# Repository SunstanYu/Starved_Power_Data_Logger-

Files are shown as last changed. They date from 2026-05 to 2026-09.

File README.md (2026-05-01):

# Starved Power Data Logger

ESP32-S3 data logger for low-power sensor collection with SD card storage and a local Wi-Fi display mode. The firmware samples soil moisture, DHT11 temperature/humidity, AS7343 spectral channels, and battery voltage, then appends periodic records to a single SD card log file.

## Hardware Target

- Board: Adafruit Feather ESP32-S3 No PSRAM
- Framework: Arduino through PlatformIO
- Storage: SPI SD card by default
- Sensors:
  - DHT11 temperature/humidity sensor
  - Analog soil moisture sensor
  - SparkFun AS7343 spectral sensor over I2C
- Battery monitor: ADC voltage divider, expected 200k upper / 100k lower

## Pin Map

| Function | Pin |
| --- | --- |
| Mode switch | GPIO5 |
| DHT11 data | A3 |
| Soil moisture ADC | A4 |
| Battery ADC | A2 |
| SD card CS | T12 |
| Battery LED | T13 |
| Peripheral switch 1 | T10 |
| Peripheral switch 2 | T6 |
| Peripheral switch 3 | T9 |
| AS7343 I2C SDA | GPIO3 |
| AS7343 I2C SCL | GPIO4 |

The SD card uses the board's default SPI pins. Only CS is configured explicitly.

## Operating Modes

GPIO5 selects the runtime mode:

- LOW: logger mode
- HIGH: local display mode

In logger mode, the device samples sensors, records data periodically, then enters timed deep sleep. GPIO5 is also configured as an EXT0 wake source, so driving GPIO5 HIGH can wake the device into display mode.

In display mode, the ESP32-S3 starts a local Wi-Fi access point and serves a dashboard from the device.

Display access point:

- SSID: `ESP32S3-Gateway`
- Password: `12345678`
- URL: `http://192.168.10.1/`

To leave display mode, hold GPIO5 LOW for 5 seconds. The firmware restarts and returns to logger mode.

## Sampling and Storage

Current logger timing:

- Awake window: 20 seconds
- Deep sleep duration: 10 seconds
- Record interval: every 50 samples

Storage mode is currently SD card:

```cpp
const int STORAGE_MODE = 0;
```

The SD card is initialized with a conservative SPI frequency:

```cpp
SD.begin(SDcardPin, SPI, 1000000);
```

Records are appended to:

```text
/sensor_log.txt
```

## Log Format

Each record is one line of comma-separated `key=value` fields:

```text
time_ms=23034,time=2027-02-13 01:31:08,sensor=Soil moisture + DHT11 + AS7343,sample_count=100,moisture=4095,voltage_mv=4670,temp_c=24.1,humidity=23.0,spectral=0|0|0|0|0|2|0|0|0|0|0|2|0|0|0|0|0|2
```

Fields:

- `time_ms`: milliseconds since the current boot
- `time`: system time if the ESP32 time source is valid
- `sensor`: sensor stack label
- `sample_count`: retained sample counter
- `moisture`: raw ADC reading from the soil moisture sensor
- `voltage_mv`: calculated battery voltage in millivolts
- `temp_c`: DHT11 temperature in Celsius, or `nan` on failed read
- `humidity`: DHT11 relative humidity, or `nan` on failed read
- `spectral`: AS7343 channel values separated by `|`

Note: `time_ms` resets after deep sleep because the chip restarts. The `time` field is only trustworthy after a valid time source is configured.

## Battery Voltage Calculation

The firmware assumes a 200k / 100k divider:

```text
Vadc = Vbat / 3
Vbat = Vadc * 3
```

The calculation is:

```cpp
int raw = analogRead(batteryAdcPin);
float vadc = ((float)raw / 4095.0f) * 3.3f;
float vbat = vadc * 3.0f;
int batteryMv = (int)(vbat * 1000.0f);
```

ADC setup:

```cpp
analogReadResolution(12);
analogSetPinAttenuation(batteryAdcPin, ADC_11db);
```

The battery measurement point should be the battery positive terminal through the divider. Do not hard-wire USB/VBUS and the battery positive terminal together unless the board's power path explicitly supports that connection.

## Build and Upload

Install PlatformIO, then run:

```sh
pio run
```

Upload to the board:

```sh
pio run --target upload
```

Open the serial monitor:

```sh
pio device monitor --baud 115200
```

## Project Layout

```text
.
├── platformio.ini
├── partitions.csv
├── src
│   ├── main.cpp
│   ├── display_gateway.cpp
│   └── display_gateway.h
├── include
├── lib
└── test
```

## Notes

- `.pio` build output is ignored by Git.
- The project includes an FFat partition, but the active storage mode is SD card.
- The display dashboard reads the same storage source used by the logger.
- If the AS7343 values saturate, reduce gain or integration time in the sensor configuration.
- If soil moisture stays near 4095, verify the sensor output range and ADC wiring.

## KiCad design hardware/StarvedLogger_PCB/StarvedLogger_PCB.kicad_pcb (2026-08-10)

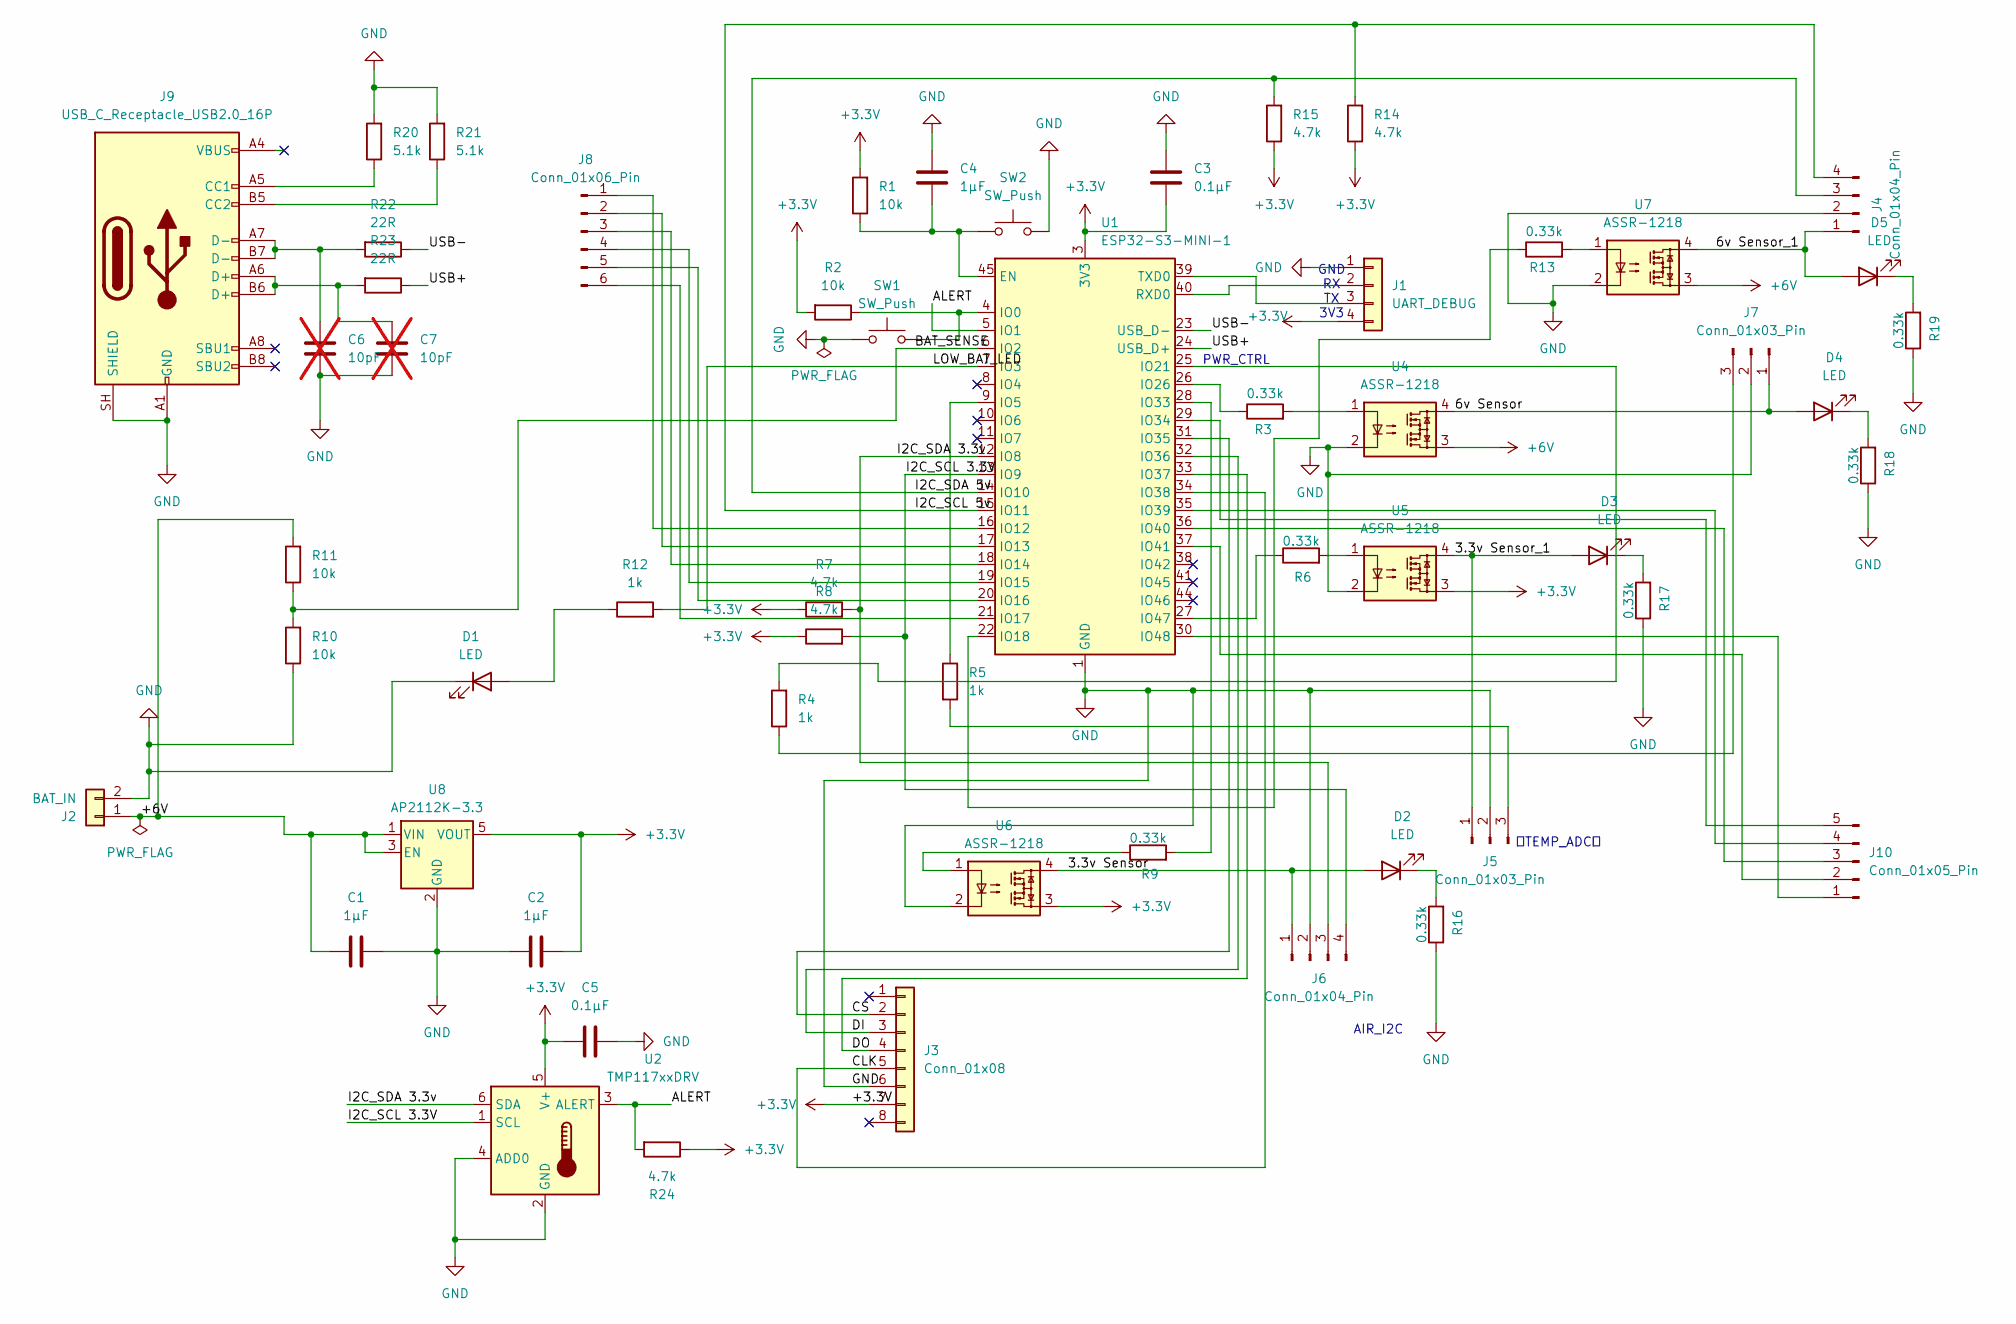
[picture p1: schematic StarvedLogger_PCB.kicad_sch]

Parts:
C1, C2, C4: 1µF; C_0603_1608Metric
C3, C5: 0.1µF; C_0603_1608Metric
C6, C7: 10pF; C_0603_1608Metric; not fitted
D1, D2, D3, D4, D5: LED; LED_0603_1608Metric
J1: UART_DEBUG; PinHeader_1x04_P2.54mm_Vertical
J2: BAT_IN; PinHeader_1x02_P2.54mm_Vertical
J3: Conn_01x08; PinHeader_1x08_P2.54mm_Vertical
J4, J6: Conn_01x04_Pin; PinHeader_1x04_P2.54mm_Vertical
J5, J7: Conn_01x03_Pin; PinHeader_1x03_P2.54mm_Vertical
J8: Conn_01x06_Pin; PinHeader_1x06_P2.54mm_Vertical
J9: USB_C_Receptacle_USB2.0_16P; USB_C_Receptacle_Amphenol_12401610E4-2A_CircularHoles
J10: Conn_01x05_Pin; PinHeader_1x05_P2.54mm_Vertical
R1, R2, R10, R11: 10k; R_0603_1608Metric
R3, R6, R9, R13, R16, R17, R18, R19: 0.33k; R_0603_1608Metric
R4, R5, R12: 1k; R_0603_1608Metric
R7, R8, R14, R15, R24: 4.7k; R_0603_1608Metric
R20, R21: 5.1k; R_0603_1608Metric
R22, R23: 22R; R_0603_1608Metric
SW1, SW2: SW_Push; SW_SPST_TL3342
U1: ESP32-S3-MINI-1
U2: TMP117xxDRV; WSON-6-1EP_2x2mm_P0.65mm_EP1x1.6mm
U4, U5, U6, U7: ASSR-1218; SO-4_4.4x4.3mm_P2.54mm
U8: AP2112K-3.3; SOT-23-5

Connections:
+3.3V: C2.2, C3.2, C5.1, J1.4, J3.7, R1.2, R2.2, R7.1, R8.1, R14.1, R15.1, R24.1, U1.3 (3V3), U2.5 (V+), U5.3, U6.3, U8.5 (VOUT)
+6V: C1.1, J2.1, R11.2, U4.3, U7.3, U8.1 (VIN), U8.3 (EN)
/3.3v Sensor: D2.2 (A), J6.1, U6.4
/3.3v Sensor_1: D3.2 (A), J5.1, U5.4
/6v Sensor: D4.2 (A), J7.1, U4.4
/6v Sensor_1: D5.2 (A), J4.1, U7.4
/ALERT: R24.2, U1.5 (IO1), U2.3 (ALERT)
/BAT_SENSE: R10.2, R11.1, U1.6 (IO2)
/CLK: J3.5, U1.34 (IO38)
/CS: J3.2, U1.31 (IO35)
/DI: J3.3, U1.32 (IO36)
/DO: J3.4, U1.33 (IO37)
/I2C_SCL 3.3V: J6.4, R8.2, U1.13 (IO9), U2.1 (SCL)
/I2C_SCL 5v: J4.4, R14.2, U1.15 (IO11)
/I2C_SDA 3.3v: J6.3, R7.2, U1.12 (IO8), U2.6 (SDA)
/I2C_SDA 5v: J4.3, R15.2, U1.14 (IO10)
/LOW_BAT_LED: R12.2, U1.7 (IO3)
/USB+: R23.1, U1.24 (USB_D+)
/USB-: R22.1, U1.23 (USB_D-)
GND: C1.2, C2.1, C3.1, C4.1, C5.2, C6.1, C7.1, D1.1 (K), J1.1, J2.2, J3.6, J4.2, J5.2, J6.2, J7.2, J9.A1 (GND), J9.A12 (GND), J9.B1 (GND), J9.B12 (GND), J9.SH (SHIELD), R10.1, R16.1, R17.1, R18.1, R19.1, R20.2, R21.2, SW1.1, SW2.2, U1.1 (GND), U1.2 (GND), U1.42 (GND), U1.43 (GND), U1.46 (GND), U1.47 (GND), U1.48 (GND), U1.49 (GND), U1.50 (GND), U1.51 (GND), U1.52 (GND), U1.53 (GND), U1.54 (GND), U1.55 (GND), U1.56 (GND), U1.57 (GND), U1.58 (GND), U1.59 (GND), U1.60 (GND), U1.61 (GND), U1.62 (GND), U1.63 (GND), U1.64 (GND), U1.65 (GND), U2.2 (GND), U2.4 (ADD0), U4.2, U5.2, U6.2, U7.2, U8.2 (GND)
unnamed: C6.2, J9.A7 (D-), J9.B7 (D-), R22.2
unnamed: C7.2, J9.A6 (D+), J9.B6 (D+), R23.2
unnamed: D1.2 (A), R12.1
unnamed: D2.1 (K), R16.2
unnamed: D3.1 (K), R17.2
unnamed: D4.1 (K), R18.2
unnamed: D5.1 (K), R19.2
unnamed: J1.2, U1.40 (RXD0)
unnamed: J1.3, U1.39 (TXD0)
unnamed: J5.3, R5.2
unnamed: J7.3, R4.1
unnamed: J8.1, U1.16 (IO12)
unnamed: J8.2, U1.17 (IO13)
unnamed: J8.3, U1.18 (IO14)
unnamed: J8.4, U1.19 (IO15)
unnamed: J8.5, U1.20 (IO16)
unnamed: J8.6, U1.21 (IO17)
unnamed: J9.A5 (CC1), R20.1
unnamed: J9.B5 (CC2), R21.1
unnamed: J10.1, U1.30 (IO48)
unnamed: J10.2, U1.37 (IO41)
unnamed: J10.3, U1.36 (IO40)
unnamed: J10.4, U1.35 (IO39)
unnamed: J10.5, U1.29 (IO34)
unnamed: R3.2, U4.1
unnamed: R6.2, U5.1
unnamed: R9.1, U6.1
unnamed: R13.2, U7.1
unnamed: C4.2, R1.1, SW2.1, U1.45 (EN)
unnamed: R2.1, SW1.2, U1.4 (IO0)
unnamed: R5.1, U1.9 (IO5)
unnamed: R13.1, U1.22 (IO18)
unnamed: R4.2, U1.25 (IO21)
unnamed: R3.1, U1.26 (IO26)
unnamed: R9.2, U1.28 (IO33)
unnamed: R6.1, U1.27 (IO47)

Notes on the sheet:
AIR_I2C
PWR_CTRL
GND RX TX 3V3
（TEMP_ADC）

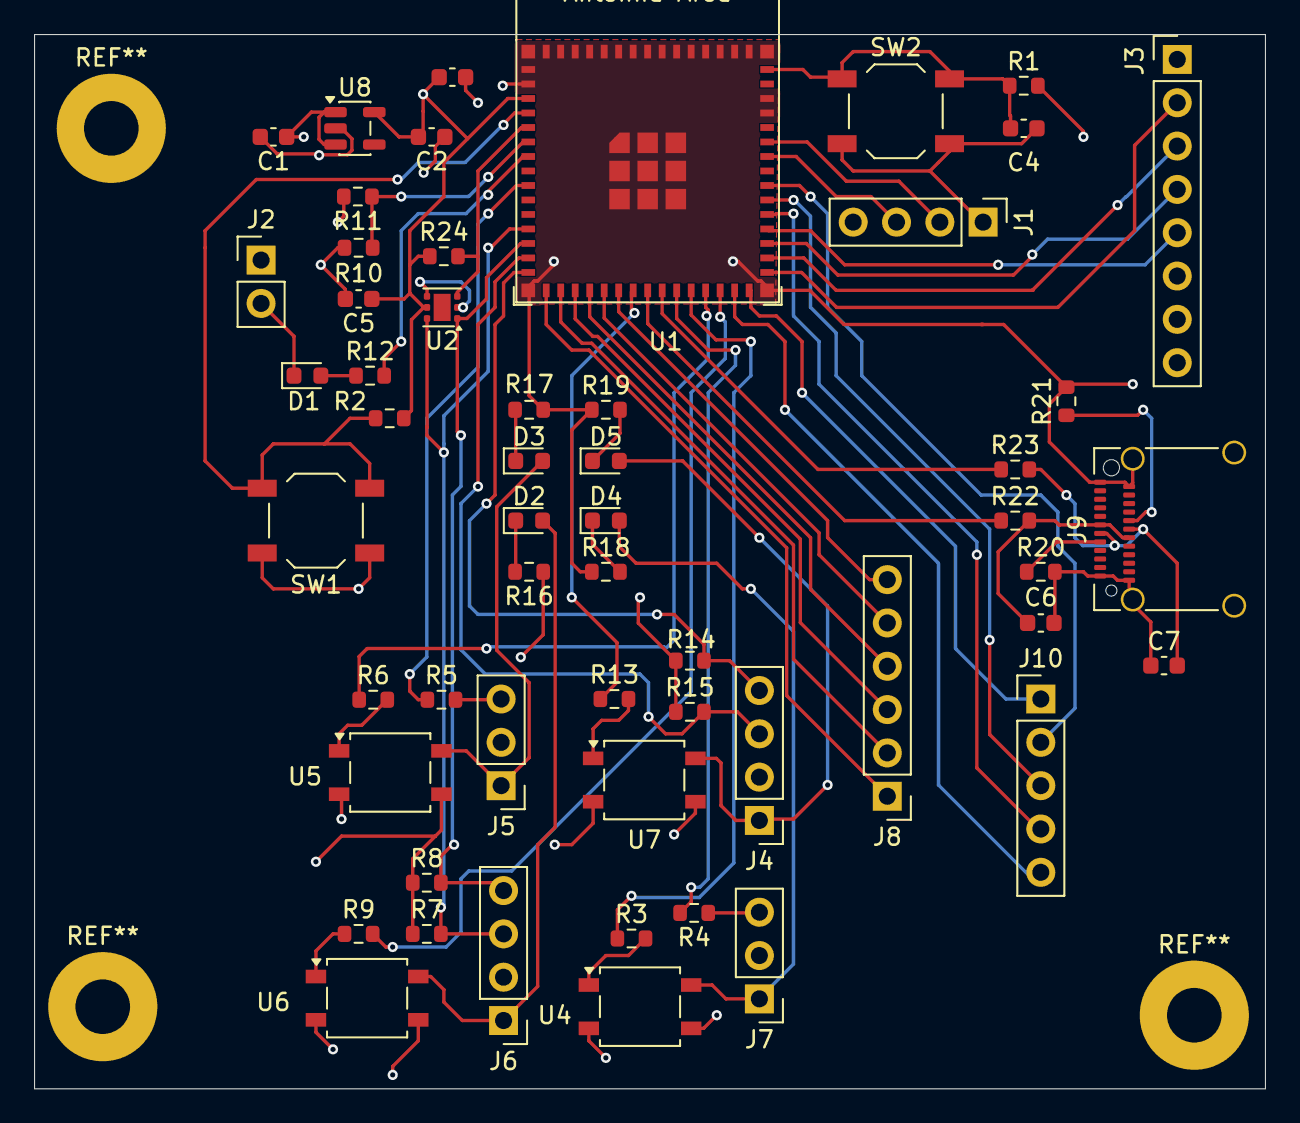
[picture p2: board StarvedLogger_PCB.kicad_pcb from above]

Board: 4 copper layers, 72.2 x 61.8 mm, 55 parts (0 on the bottom side), 56 nets.

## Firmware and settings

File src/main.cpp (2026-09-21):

#include <Arduino.h>
#include "esp_sleep.h"
#include "driver/gpio.h"  // for access to gpio_num_t / GPIO_NUM_6
#include <SPI.h>
#include <SD.h>
#include <FFat.h>
#include <Wire.h>
#include <DHTesp.h>
#include <SparkFun_AS7343.h>
#include <time.h>
#include "display_gateway.h"
#include "tasks.h"

// ====================== CONSTANTS & PINS ======================
const uint64_t SLEEP_DURATION_US = 10 * 1000000;   // sleep for 10 seconds
const uint32_t AWAKE_DURATION_MS = 20 * 1000;      // awake for 20 seconds
const uint32_t MODE_SWITCH_DELAY_MS = 5000;         // GPIO5 must stay LOW for 5s before leaving display mode
const uint32_t RECORD_EVERY_SAMPLE_COUNT = 50;      // write one record every 50 samples
const int STORAGE_MODE = 0;                         // 0 = SD card, 1 = FFat flash
int led = LED_BUILTIN;
const gpio_num_t modePin = GPIO_NUM_5;              // LOW = logger mode, HIGH = display mode

const int switch1Pin = T10;
const int switch2Pin = T6;
const int switch3Pin = T9;
const int batteryLedPin = T13;


const int sensor1Pin = A3;   // DHT11 data pin, use the real GPIO number 
const int sensor2Pin = A4;    // soil moisture sensor analog input
const int SDcardPin = T12;
const int batteryAdcPin = A2;
const char* DISPLAY_SENSOR_TYPE = "Soil moisture + DHT11 + AS7343";
const char* DISPLAY_DATA_FILE = "/sensor_log.txt";
const float ADC_VREF = 3.3f;
const float BATTERY_DIVIDER_RATIO = 3.0f;
const float BATTERY_LOW_THRESHOLD_V = 4.0f;

// ★ A5：低电压截止。
//
// 供电是 4 节 AA（标称 6.0V）。碱性电池没有锂电「过放即报废」的问题，
// 所以这里的理由不是保护电池，而是【保护数据】：
// 电压掉到 3.3V LDO 的压差余量以下时，轨会不稳；如果恰好发生在
// SD 写入中途，坏的是文件甚至整张卡——而那是几个月的数据。
//
// 所以到阈值就：刷掉待写数据 → 点亮低电量灯 → 进【无定时唤醒】的深睡。
// 不设定时器意味着它不会再自己醒来采样，只能靠 EXT0（人拨开关）或换电池。
// extern：C++ 里命名空间作用域的 const 默认是【内部链接】，
// 不加 extern 的话 tasks.cpp 链接时找不到它。
extern const float BATTERY_CUTOFF_V = 3.7f;

// ★ A5 修（2026-09-20 上板实测发现）
//
// 【现象】把固件烧进一块【没接电池】的裸板，上电不到 1 秒就永久睡死，
// USB 从系统里彻底消失，esptool 也够不着，只能按 RESET 救。
//
// 【原因】判据写的是 `batteryMv > 0`，本意是「读数有效」。
// 但 batteryAdcPin 悬空时 ADC 不读 0 —— 它读到的是几百 mV 的噪声。
// 于是 `> 0 && < 3700` 成立，节点认为自己没电了，执行永久停机。
//
// 【为什么这在田里是致命的】分压电阻虚焊、接插件松动、电池仓接触不良 ——
// 任何一种都会让 ADC 悬空，节点就把自己变成砖，而且【没有唤醒源】，
// 必须有人走到田里按复位。本来是保护数据的机制，变成了失效机制。
//
// 两道闸：
//   ① 合理性下限：4 节 AA 经 ÷3 分压，哪怕快没电也在 3V 以上。
//      读到低于 1V 说明【没接电池 / ADC 悬空】，不是「电池空了」。
//   ② 连续判定：单次 ADC 毛刺不该让一个田间节点停机。
// ★ 第二次修（第一次的判据是错的，上板又睡死一次才发现）
//
// 第一版下限设 1000mV，依据是「悬空 ADC 读数低」。**这个假设不成立** ——
// 悬空引脚读的是随机的中间值，不是 0 附近。分压比 3:1，ADC 只要落在
// 0.33~1.23V，换算出来就是 1.0~3.7V，正好落进低电量窗口，
// 连续 3 次照样停机。加了连续判定只是把「1 秒睡死」变成「90 秒睡死」。
//
// 【按物理量重新定界】供电是 4 节 AA 碱性电池：
//     满电 6.4V ·  标称 6.0V ·  0.9V/节 = 3.6V 已经耗尽
// 所以 3.7V 截止是对的。但 3.0V（0.75V/节）是**深度放空**，
// 一个还能跑 WiFi 的节点不可能读到这个值 —— 读到就说明【线路断了】，
// 不是电池空了。下限提到 3000mV，可动作窗口变成 3.0~3.7V。
//
// 【再加一道：稳定性】电平本身区分不了悬空和真电压，但**噪声能**：
// 接了电池经分压出来的读数是稳的，悬空引脚会飘。
// 所以不只要连续 3 次低，还要这 3 次的极差小于 300mV。
const int BATTERY_SANITY_FLOOR_MV = 3000;   // 0.75V/节 = 深度放空，读到只能是线路断了
const int BATTERY_LOW_STREAK = 3;           // 连续 3 次
const int BATTERY_STABLE_SPREAD_MV = 300;   // 这 3 次的极差上限——悬空会飘，电池不会

// 返回 true 表示「确实该停机了」。
bool batteryShouldShutdown(int batteryMv) {
  static int streak = 0;
  static int lo = 0, hi = 0;

#ifdef BENCH_NO_BATTERY
  // ★ 独立开关，不再跟 FORCE_DISPLAY_MODE 绑在一起。
  //
  // 这两个是【两件事】：FORCE_DISPLAY_MODE 是「没接跳线」，
  // BENCH_NO_BATTERY 是「没接电池」。第一版把旁路写在
  // #ifdef FORCE_DISPLAY_MODE 里，结果台面验证时这个函数【一进来就返回】，
  // 下面那两道判据（合理性下限、稳定性）一次都没在真硬件上跑过 ——
  // 而它们恰恰是那个把板子睡死两次的 bug 的修复本身。
  //
  // 耦合两个无关的开关，等于让其中一个永远测不到。
  Serial.printf("[BAT] %d mV (bench: low-battery shutdown disabled)\n", batteryMv);
  return false;
#endif

  if (batteryMv < BATTERY_SANITY_FLOOR_MV) {
    streak = 0;
    Serial.printf("[BAT] %d mV below sanity floor %d -> NO BATTERY / wiring fault, "
                  "not low battery\n", batteryMv, BATTERY_SANITY_FLOOR_MV);
    return false;                       // 线路断了，绝不停机
  }
  if (batteryMv >= (int)(BATTERY_CUTOFF_V * 1000)) {
    streak = 0;
    return false;
  }

  if (streak == 0) { lo = hi = batteryMv; }
  else { if (batteryMv < lo) lo = batteryMv; if (batteryMv > hi) hi = batteryMv; }
  streak++;

  if (streak < BATTERY_LOW_STREAK) {
    Serial.printf("[BAT] %d mV below cutoff (%d/%d) — waiting for confirmation\n",
                  batteryMv, streak, BATTERY_LOW_STREAK);
    return false;
  }
  if (hi - lo > BATTERY_STABLE_SPREAD_MV) {
    Serial.printf("[BAT] readings unstable (spread %d mV > %d) -> floating pin, "
                  "not a dying battery\n", hi - lo, BATTERY_STABLE_SPREAD_MV);
    streak = 0;
    return false;                       // 飘 = 悬空，不是电池在掉电
  }
  return true;
}
DHTesp dht;
SfeAS7343ArdI2C spectralSensor;
uint16_t spectralChannels[ksfAS7343NumChannels];
// const int wakePin   = T6;    // D6 = GPIO6 (used as normal input + DeepSleep wakeup)
bool forever_awake  = false; // never sleep after D6 is triggered

bool sdReady = false;
bool flashReady = false;
bool spectralReady = false;
bool displayModeActive = false;
bool tasksRunning = false;      // ★ A8：四任务是否起来了
bool modePinLowTiming = false;
unsigned long modePinLowStartMs = 0;
RTC_DATA_ATTR uint32_t sampleCounter = 0;

// ====================== HELPERS ======================

// ★ A10：OTA 回滚自检。
//
// Arduino 核心已启用 CONFIG_BOOTLOADER_APP_ROLLBACK_ENABLE：新固件首次
// 启动时处于 PENDING_VERIFY 状态，initArduino() 会调 verifyOta()——
// 返回 true 就 mark_app_valid 确认，返回 false 就【自动回滚并重启】到旧分区。
//
// 但核心里的 verifyOta() 是 weak 函数，默认无条件 `return true`：
// 只要新固件能跑到 initArduino() 就算通过。这挡得住「根本起不来」，
// 挡不住「能起来但功能坏了」。
//
// 对一个埋在田里、回收成本极高的节点，这个区别是致命的——
// 刷坏了就是报废，没有第二次机会。所以覆盖它，做真实自检。
//
// ⚠️ 核心注释提醒：这函数在启动早期跑，要短、不要阻塞太久。
// 所以这里只做「能不能起来」级别的检查，不碰 2.5s 的 DHT11 时序。
extern "C" bool verifyOta() {
  Serial.println("[OTA] verifying new image...");

  pinMode(SDcardPin, OUTPUT);
  digitalWrite(SDcardPin, HIGH);
  if (!SD.begin(SDcardPin, SPI, 1000000)) {
    Serial.println("[OTA] FAIL: SD not available -> rollback");
    return false;                          // 存储起不来 = 数据会丢，不如退回
  }
  SD.end();

  // 同一个坑：`mv > 0` 挡不住悬空 ADC。分压虚焊会让每次 OTA 都无条件回滚，
  // 而回滚是【静默】的 —— 你只会看到"升级没生效"，查不到为什么。
  int mv = getBatteryMv();
  if (mv >= BATTERY_SANITY_FLOOR_MV && mv < (int)(BATTERY_CUTOFF_V * 1000)) {
    Serial.printf("[OTA] FAIL: battery %d mV too low -> rollback\n", mv);
    return false;                          // 电量不够撑过验证期，别冒险留在新版
  }

  Serial.println("[OTA] image verified, cancelling rollback.");
  return true;
}

// ★ A5：电量到底线时的收尾动作。调用后不返回。
void enterLowBatteryShutdown(int batteryMv) {
  Serial.printf("[BAT] %d mV below cutoff %.2f V — flushing and halting.\n",
                batteryMv, BATTERY_CUTOFF_V);
  digitalWrite(batteryLedPin, HIGH);
  setPeripheralSwitches(false);          // 先断外设，减少残余放电
  Serial.flush();

  // ★ 改：留一个【很长周期】的定时唤醒，而不是彻底不醒。
  //
  // 原设计是无唤醒源，理由是「不会再自己醒来采样」。但那等于
  // 把「需要人工干预」写死进固件 —— 而碱性电池在低温下电压会回升，
  // 白天升温后可能又能撑一阵；分压虚焊修好后也该能自己恢复。
  //
  // 6 小时醒一次只是读个 ADC 再睡，占空比接近 0，
  // 对续航的影响可以忽略，换来的是【可恢复】。
  esp_sleep_enable_timer_wakeup(6ULL * 3600ULL * 1000000ULL);
  esp_deep_sleep_start();
}

// ★ A6：资源水位。诊断「跑久了会不会崩」只能靠这个，不能靠推测。
//
// getMinFreeHeap() 是【历史最低值】——它回答的是「最危险的那一刻离
// OOM 还有多远」，比当前空闲值有用得多。栈水位同理：uxTaskGetStack-
// HighWaterMark 返回的是该任务栈的历史最小剩余字节。
void logResourceWatermark(const char* tag) {
  Serial.printf("[MEM] %s heap=%u min=%u largest=%u stack_free=%u\n",
                tag,
                ESP.getFreeHeap(),
                ESP.getMinFreeHeap(),                        // 历史最低 ← 关键
                ESP.getMaxAllocHeap(),                       // 最大连续块 ← 看碎片
                uxTaskGetStackHighWaterMark(NULL) * sizeof(StackType_t));
}

// ★ A4：Task WDT。田里的节点卡死 = 报废，只能人去拔电池。
//
// Arduino 默认【关掉】了 task WDT（原型阶段谁也不想跑着跑着被复位），
// 但生产设备必须有人盯着「卡死」这件事：SD 总线卡住、传感器不应答、
// 某个 while 等不到条件——这些都不会自己恢复。
//
// 采样态与显示态的超时不同：采样一轮含 2.5s 的外设稳定与 DHT11 时序，
// 显示态则是持续响应 HTTP。所以由调用方给超时值。
#include "esp_task_wdt.h"

void watchdogBegin(uint32_t timeout_s) {
#if ESP_IDF_VERSION_MAJOR >= 5
  esp_task_wdt_config_t cfg = {
      .timeout_ms = timeout_s * 1000,
      .idle_core_mask = 0,          // 不监控 idle 任务
      .trigger_panic = true,        // 超时直接 panic 复位（现场会进 coredump）
  };
  esp_task_wdt_reconfigure(&cfg);
#else
  esp_task_wdt_init(timeout_s, true);
#endif
  esp_task_wdt_add(NULL);           // 把当前任务纳入监控
  Serial.printf("[WDT] armed, timeout=%us\n", timeout_s);
}

void watchdogFeed() { esp_task_wdt_reset(); }
void setPeripheralSwitches(bool enabled) {
  digitalWrite(switch1Pin, enabled ? HIGH : LOW);
  digitalWrite(switch2Pin, enabled ? HIGH : LOW);
  digitalWrite(switch3Pin, enabled ? HIGH : LOW);
  Serial.printf(
    "[PWR] switch1=%s switch2=%s switch3=%s\n",
    enabled ? "HIGH" : "LOW",
    enabled ? "HIGH" : "LOW",
    enabled ? "HIGH" : "LOW"
  );
}

// GPIO5 is the single hardware mode selector for the whole firmware:
// - LOW  => sensor logger mode
// - HIGH => local display gateway mode
bool isDisplayModeRequested() {
#ifdef FORCE_DISPLAY_MODE
  // 测试钩子：常驻模式要求 GPIO5 拉高，而那需要一根跳线。
  // 开这个宏可以在没有跳线的台面上验证四任务架构本身。
  // 只由 -DFORCE_DISPLAY_MODE 打开，正常构建里这段不存在。
  return true;
#endif
  return digitalRead((int)modePin) == HIGH;
}

void printWakeupReason() {
  esp_sleep_wakeup_cause_t cause = esp_sleep_get_wakeup_cause();
  switch (cause) {
    case ESP_SLEEP_WAKEUP_EXT0:
      Serial.println("[WAKE] Wakeup caused by EXT0 (GPIO5 HIGH).");
      break;
    case ESP_SLEEP_WAKEUP_TIMER:
      Serial.println("[WAKE] Wakeup caused by timer.");
      break;
    default:
      Serial.printf("[WAKE] Wakeup was not caused by deep sleep: %d\n", (int)cause);
      break;
  }
}

// Logger mode uses both wake sources:
// 1. timer wakeup for the next sampling cycle
// 2. EXT0 wakeup on GPIO5 HIGH so the user can force display mode while asleep
void configureWakeSources() {
  esp_sleep_enable_timer_wakeup(SLEEP_DURATION_US);
  esp_sleep_enable_ext0_wakeup(modePin, 1);
}

// A reboot is the cleanest way to switch modes at runtime because setup()
// re-runs the same initialization path and re-evaluates GPIO5.
void restartForModeSwitch(const char* reason) {
  Serial.println(reason);
  Serial.flush();
  delay(100);
  ESP.restart();
}

void enterTimedDeepSleep() {
  Serial.println("[SLEEP] Preparing to enter deep sleep...");
  configureWakeSources();
  Serial.println("[SLEEP] Entering deep sleep now.");
  Serial.flush();
  delay(100);
  esp_deep_sleep_start();
}

int getMoisture() {
  int value = analogRead(sensor2Pin);
  Serial.print("Soil moisture raw value: ");
  Serial.println(value);
  return value;
}

int getBatteryMv() {
  int raw = analogRead(batteryAdcPin);
  float vadc = ((float)raw / 4095.0f) * ADC_VREF;
  float vbat = vadc * BATTERY_DIVIDER_RATIO;
  int batteryMv = (int)(vbat * 1000.0f);

  Serial.print("[BAT] RAW=");
  Serial.print(raw);
  Serial.print(" Vbat=");
  Serial.print(vbat, 3);
  Serial.println(" V");

  digitalWrite(batteryLedPin, vbat < BATTERY_LOW_THRESHOLD_V ? HIGH : LOW);
  Serial.printf("[BAT] T13=%s\n", vbat < BATTERY_LOW_THRESHOLD_V ? "HIGH" : "LOW");

  return batteryMv;
}

bool readDht11(float& temperatureC, float& humidity) {
  Serial.println("[DHT11] Reading...");
  TempAndHumidity data = dht.getTempAndHumidity();
  humidity = data.humidity;
  temperatureC = data.temperature;

  if (isnan(humidity) || isnan(temperatureC)) {
    Serial.println("[DHT11] Failed to read from DHT11");
    return false;
  }

  Serial.print("[DHT11] Temperature: ");
  Serial.print(temperatureC);
  Serial.print(" C, Humidity: ");
  Serial.print(humidity);
  Serial.println(" %");
  return true;
}

bool initSpectralSensor() {
  Serial.println("[AS7343] Initializing...");
  Wire.begin(3,4);
  Wire.setClock(100000);

  if (!spectralSensor.begin(0x39, Wire)) {
    Serial.println("[AS7343] begin failed.");
    return false;
  }
  if (!spectralSensor.powerOn()) {
    Serial.println("[AS7343] powerOn failed.");
    return false;
  }
  if (!spectralSensor.setAutoSmux(AUTOSMUX_18_CHANNELS)) {
    Serial.println("[AS7343] setAutoSmux failed.");
    return false;
  }
  if (!spectralSensor.enableSpectralMeasurement()) {
    Serial.println("[AS7343] enableSpectralMeasurement failed.");
    return false;
  }

  Serial.println("[AS7343] Sensor ready.");
  return true;
}

int readSpectralChannels(uint16_t* channels, size_t channelCapacity) {
  if (!spectralReady) {
    return 0;
  }

  if (!spectralSensor.readSpectraDataFromSensor()) {
    Serial.println("[AS7343] readSpectraDataFromSensor failed.");
    return 0;
  }

  int count = spectralSensor.getData(channels);
  if (count > (int)channelCapacity) {
    count = (int)channelCapacity;
  }

  Serial.print("[AS7343] Channels: ");
  for (int i = 0; i < count; i++) {
    Serial.print(channels[i]);
    if (i + 1 < count) {
      Serial.print(",");
    }
  }
  Serial.println();
  return count;
}

bool initSdCard() {
  Serial.printf("[SD] Initializing with CS pin %d...\n", SDcardPin);
  SPI.begin();
  pinMode(SDcardPin, OUTPUT);
  digitalWrite(SDcardPin, HIGH);
  if (!SD.begin(SDcardPin, SPI, 1000000)) {
    Serial.println("[SD] SD.begin failed.");
    return false;
  }
  Serial.println("[SD] SD.begin OK.");
  return true;
}

bool initFlashStorage() {
  Serial.println("[FFat] Mounting flash storage...");
  if (!FFat.begin(true)) {
    Serial.println("[FFat] FFat.begin failed.");
    return false;
  }
  Serial.println("[FFat] FFat mounted OK.");
  return true;
}

bool isStorageReady() {
  return STORAGE_MODE == 0 ? sdReady : flashReady;
}

const char* getStorageName() {
  return STORAGE_MODE == 0 ? "SD" : "FFat";
}

String getDisplayStorageLabel() {
  return STORAGE_MODE == 0 ? "SD card log" : "FFat flash files";
}

String buildMeasurementRecord(
  int moisture,
  int batteryMv,
  float temperatureC,
  float humidity,
  bool dhtOk,
  const uint16_t* channels,
  int channelCount
) {
  time_t now = time(nullptr);
  struct tm timeinfo;
  String record;

  record += "time_ms=";
  record += String(millis());
  if (now > 1700000000 && localtime_r(&now, &timeinfo) != nullptr) {
    char timestamp[24];
    snprintf(
      timestamp,
      sizeof(timestamp),
      "%04d-%02d-%02d %02d:%02d:%02d",
      timeinfo.tm_year + 1900,
      timeinfo.tm_mon + 1,
      timeinfo.tm_mday,
      timeinfo.tm_hour,
      timeinfo.tm_min,
      timeinfo.tm_sec
    );
    record += ",time=";
    record += timestamp;
  }
  record += ",sensor=";
  record += DISPLAY_SENSOR_TYPE;
  record += ",sample_count=";
  record += String(sampleCounter);
  record += ",moisture=";
  record += String(moisture);
  record += ",voltage_mv=";
  record += String(batteryMv);
  // ★ A7：显式的数据质量位。
  //
  // 原来读失败写 "nan"，但下游分不清三件事：传感器读失败、传感器真的
  // 返回了 NaN、解析出错。在 esp32-autoflash 的评测里正好栽过同一个坑
  // ——「读数恒 0」到底是代码写坏了还是传感器坏了，只看数值无法归因。
  // 带上质量位，归因就从「猜」变成「读一个字段」。
  record += ",temp_c=";
  record += dhtOk ? String(temperatureC, 1) : String("nan");
  record += ",humidity=";
  record += dhtOk ? String(humidity, 1) : String("nan");
  record += ",dht_q=";
  record += dhtOk ? "ok" : "read_fail";
  // ★ A3：时钟来源。没对过时只有相对时间（time_ms + 采样序号），
  // 下游据此判断 time= 字段可不可信，而不是看到有值就当真。
  record += ",clk=";
  record += (now > 1700000000) ? "synced" : "uptime_only";
  record += ",spectral=";
  if (channelCount > 0) {
    for (int i = 0; i < channelCount; i++) {
      record += String(channels[i]);
      if (i + 1 < channelCount) {
        record += "|";
      }
    }
  } else {
    record += "none";
  }
  return record;
}

String buildFlashRecordPath() {
  time_t now = time(nullptr);
  struct tm timeinfo;
  char path[48];

  if (now > 1700000000 && localtime_r(&now, &timeinfo) != nullptr) {
    snprintf(
      path,
      sizeof(path),
      "/%04d%02d%02d_%02d%02d%02d.txt",
      timeinfo.tm_year + 1900,
      timeinfo.tm_mon + 1,
      timeinfo.tm_mday,
      timeinfo.tm_hour,
      timeinfo.tm_min,
      timeinfo.tm_sec
    );
  } else {
    snprintf(path, sizeof(path), "/sample_%010lu_%010lu.txt", (unsigned long)sampleCounter, (unsigned long)millis());
  }

  return String(path);
}

void appendMeasurementToSd(const String& record) {
  if (!sdReady) {
    return;
  }

  File file = SD.open(DISPLAY_DATA_FILE, FILE_APPEND);
  if (!file) {
    Serial.println("[SD] Open display data file failed.");
    return;
  }

  file.println(record);
  file.close();
  Serial.println("[SD] Measurement appended.");
}

void writeMeasurementToFlash(const String& record) {
  if (!flashReady) {
    return;
  }

  String path = buildFlashRecordPath();
  File file = FFat.open(path.c_str(), FILE_WRITE);
  if (!file) {
    Serial.printf("[FFat] Open flash data file failed: %s\n", path.c_str());
    return;
  }

  file.println(record);
  file.close();
  Serial.printf("[FFat] Measurement written: %s\n", path.c_str());
}

// ★ A8：存储访问的 RAII 锁。
//
// 下面几个函数都有多个提前返回路径，手工配对 storageLock/storageUnlock
// 迟早会漏掉一条 —— 漏一次就是永久死锁。让析构函数去做。
//
// 四任务没起来时 storageLock() 是空操作，所以 logger 模式不受影响。
struct StorageGuard {
  bool held;
  explicit StorageGuard(uint32_t ms = 4000) : held(storageLock(ms)) {}
  ~StorageGuard() { if (held) storageUnlock(); }
};

void writeMeasurementRecord(const String& record) {
  StorageGuard g;                       // ← net 任务可能正在读同一张卡
  if (STORAGE_MODE == 0) {
    appendMeasurementToSd(record);
  } else {
    writeMeasurementToFlash(record);
  }
}
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
void loop() {
  if (displayModeActive) {
    // Display mode stays awake while GPIO5 remains HIGH. When GPIO5 stays LOW
    // for MODE_SWITCH_DELAY_MS, reboot so setup() can switch back to logger mode.
    if (isDisplayModeRequested()) {
      if (modePinLowTiming) {
        Serial.println("[MODE] GPIO5 returned HIGH. Cancel logger switch countdown.");
        modePinLowTiming = false;
      }
      watchdogFeed();
      // ★ A8：任务起来后，HTTP 由 net 任务处理，loop() 不再自己跑
      if (tasksRunning) { tasksIdle(); } else { displayGatewayLoop(); }
      return;
    }

    if (!modePinLowTiming) {
      modePinLowTiming = true;
      modePinLowStartMs = millis();
      Serial.println("[MODE] GPIO5 went LOW. Start logger switch countdown...");
    } else if (millis() - modePinLowStartMs >= MODE_SWITCH_DELAY_MS) {
      restartForModeSwitch("[MODE] GPIO5 stayed LOW long enough. Restarting into logger mode.");
    }

    if (tasksRunning) { tasksIdle(); } else { displayGatewayLoop(); }
    return;
  }

  // ------------- Check D6: if HIGH, enter 'forever-awake' mode -------------
  // if (digitalRead(wakePin) == HIGH) {
  //   if (!forever_awake) {
  //     Serial.println("\n[WAKE PIN TRIGGERED] D6 = HIGH → Forever-awake mode enabled. Device will NEVER sleep anymore!");
  //     forever_awake = true;
  //   }
  // }
  watchdogFeed();
  static unsigned long start_time = millis();
  unsigned long current_time = millis();
  unsigned long elapsed_time = current_time - start_time;

  
  Serial.print("Elapsed time: ");
  Serial.print(elapsed_time / 1000);
  Serial.print("s / ");
  Serial.print(AWAKE_DURATION_MS / 1000);
  Serial.println("s");

  // LED blinking
  digitalWrite(led, HIGH);
  delay(300);
  digitalWrite(led, LOW);
  delay(300);

  // -------- If in 'forever-awake' mode, skip deep-sleep ----------
  if (forever_awake) {
    Serial.println("[INFO] Forever-awake mode active. Skipping deep-sleep...");
    delay(1000);
    return;
  }

  // ================== Normal deep-sleep flow ==================
  if (elapsed_time >= AWAKE_DURATION_MS) {
    // Allow GPIO5 HIGH to interrupt the logger cycle immediately.
    if (isDisplayModeRequested()) {
      restartForModeSwitch("[MODE] GPIO5 HIGH detected. Restarting into display mode.");
    }

    setPeripheralSwitches(true);
    delay(500);
    initializeLoggerPeripherals();

    int moisture = getMoisture();
    int batteryMv = getBatteryMv();
    if (batteryShouldShutdown(batteryMv)) {
      enterLowBatteryShutdown(batteryMv);   // 在写卡【之前】判，确保还有电落盘
    }
    float temperatureC = 0.0f;
    float humidity = 0.0f;
    bool dhtOk = readDht11(temperatureC, humidity);
    int spectralCount = readSpectralChannels(spectralChannels, ksfAS7343NumChannels);

    sampleCounter++;
    Serial.printf("[SAMPLE] Count=%lu, record every %lu samples.\n", (unsigned long)sampleCounter, (unsigned long)RECORD_EVERY_SAMPLE_COUNT);

    if (sampleCounter % RECORD_EVERY_SAMPLE_COUNT == 0) {
      if (isStorageReady()) {
        String record = buildMeasurementRecord(
          moisture,
          batteryMv,
          temperatureC,
          humidity,
          dhtOk,
          spectralChannels,
          spectralCount
        );
        writeMeasurementRecord(record);
      } else {
        Serial.printf("[%s] Storage unavailable. Measurement not recorded.\n", getStorageName());
      }
    } else {
      Serial.println("[SAMPLE] Measurement sampled but not recorded this cycle.");
    }

    logResourceWatermark("post-sample");   // 每轮落一条，跑几天就能看出趋势

    Serial.println("\n================================");
    Serial.println("Logger cycle complete. Entering timed deep sleep...");
    Serial.print("Device will wake up after ");
    Serial.print(SLEEP_DURATION_US / 1000000ULL);
    Serial.println(" seconds, or immediately if GPIO5 goes HIGH.");
    Serial.println("================================\n");

    delay(2000);
    //delay>1s才能给DHT11留出采样时间
    setPeripheralSwitches(false);
    // Deep-sleep is temporarily disabled for debugging. Keep the same timing
    // budget by delaying for the original sleep interval, then restart the
    // awake window timer for the next sample cycle.
    enterTimedDeepSleep();

    // 2) D6 HIGH wakeup (EXT0)
    //    Note: EXT0 uses RTC IO; GPIO6 is a RTC IO on ESP32-S3 and is usable
    //    second parameter 1 = wake on HIGH, 0 = wake on LOW
    // esp_sleep_enable_ext0_wakeup(GPIO_NUM_6, 1);
    
    // Enter deep-sleep (program 'powers off' here; on wake, starts from setup())
    return;
    //模拟deepsleep
    // delay(SLEEP_DURATION_US / 1000);
    
  }

  delay(500);
}

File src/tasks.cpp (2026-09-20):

// ★ A8：FreeRTOS 四任务改造
//
// ## 改之前的问题
//
// 常驻（display）模式下 loop() 里只有一句 displayGatewayLoop()。
// 它要么在等 HTTP 请求，要么在渲染页面 —— 【整个模式期间一次样都不采】。
// 所以用户看到的"实时数据"其实是上一次 logger 模式落盘的旧记录，
// 而拔下开关切回 logger 模式又意味着网页断了。
// 两件事共用一个线程，就只能二选一。
//
// ## 为什么是任务而不是状态机
//
// 也可以把 loop() 写成非阻塞状态机，但采样路径里有几段【真的阻塞】：
//   · DHT11 的单总线时序要 ~2.5s，且不能被打断
//   · SD 写入一次几十到几百 ms，取决于卡的擦写块状态
// 状态机里这些都得手工切成若干小步，每一步记住自己走到哪 ——
// 代码会变形，而且 DHT11 那段根本切不开。
//
// FreeRTOS 是抢占式的：任务可以【在任意指令处】被切走，
// 所以阻塞调用照原样写，调度器负责让别的任务继续跑。
// 代价是共享数据随时可能被切，必须自己加锁 ——
// 这正是下面 g_latestMux 的由来。
//
// ## 四个任务的划分依据：按【阻塞原因】分，不是按功能分
//
// | 任务 | 核 | 优先级 | 为什么单独一个任务 |
// | --- | --- | --- | --- |
// | Sensor  | 1 | 3 | 被 I²C / 单总线时序阻塞 |
// | Storage | 1 | 2 | 被 SPI + 文件系统阻塞，时长不可预测 |
// | Net     | 0 | 1 | 被 socket 阻塞；和 WiFi 驱动同核，少跨核传数据 |
// | Superv. | 0 | 4 | 谁都不等，所以能如实判断别人是不是卡住了 |
//
// 采样和存储之间用【队列】而不是共享缓冲区：一次 SD 写入慢下来时，
// 采样节奏不受影响，记录先在队列里排着。队列满了就丢最旧的 ——
// 对环境监测来说，新数据比旧数据有价值。
//
// 监控任务优先级最高（4）是有意的：它必须能抢占正在死等的任务，
// 否则一个卡住的低优先级任务会让"发现卡住"这件事本身也卡住。

#include "tasks.h"
#include "display_gateway.h"

#include "freertos/FreeRTOS.h"
#include "freertos/task.h"
#include "freertos/queue.h"
#include "freertos/semphr.h"
#include "esp_task_wdt.h"

// main.cpp 里的采样 / 存储原语
extern int getMoisture();
extern int getBatteryMv();
extern bool readDht11(float& temperatureC, float& humidity);
extern int readSpectralChannels(uint16_t* channels, size_t channelCapacity);
extern String buildMeasurementRecord(int moisture, int batteryMv, float temperatureC,
                                     float humidity, bool dhtOk,
                                     const uint16_t* spectralChannels, int spectralCount);
extern void writeMeasurementRecord(const String& record);
extern bool isStorageReady();
extern void setPeripheralSwitches(bool enabled);
extern void logResourceWatermark(const char* tag);
extern void enterLowBatteryShutdown(int batteryMv);
extern const float BATTERY_CUTOFF_V;
extern bool batteryShouldShutdown(int batteryMv);
extern uint16_t spectralChannels[];

// ---------------------------------------------------------------- 参数

static const uint32_t SENSOR_PERIOD_MS = 30 * 1000;   // 常驻模式下每 30s 采一次
static const uint32_t SUPERVISOR_PERIOD_MS = 5 * 1000;
static const uint32_t WDT_TIMEOUT_S = 60;             // 要盖得住 30s 采样周期 + 2.5s 时序
static const UBaseType_t RECORD_QUEUE_LEN = 4;

// ★ 队列里放的必须是 POD，不能是 String。
//
// xQueueSend 是按字节 memcpy 的。传 String 进去，复制的只是它内部那个
// 【堆指针】；发送方的局部 String 一出作用域就析构、把堆块还回去，
// 接收方拿到的指针就悬空了 —— 之后要么读到垃圾，要么二次 free 崩溃。
// 而且这种崩溃是间歇的：只有在分配器恰好复用了那块内存时才炸。
//
// 所以定长字符数组。代价是 4×264 ≈ 1KB 静态占用，换来的是不会有悬空指针。
struct RecordMsg { char line[264]; };

// 栈深。下面的数字来自 2026-09-20 的上板实测（supervisor 打的高水位），
// 不是估的：
//     sensor  4096 → 剩 1500   用掉 ~2.6K，余量仅 37%
//     storage 6144 → 剩 4996   用掉 ~1.1K
//     net     8192 → 剩 6892   用掉 ~1.3K
//     superv  3072 → 剩 1224   用掉 ~1.8K
//
// ⚠️ 但 storage / net 那两个数【不能当结论】：测试板没插 SD 卡、
// 也没发过 HTTP 请求，这两个任务最吃栈的路径（文件系统调用、
// WebServer 渲染）根本没执行。等真有卡有请求时得重测。
//
// sensor 提到 5120：37% 的余量本来就偏紧，而且这次 AS7343 初始化失败、
// 光谱读取那条路径也没走到，真实峰值只会更高。
static const uint32_t STACK_SENSOR  = 5120;   // 实测用掉 2.6K，且峰值路径未覆盖
static const uint32_t STACK_STORAGE = 6144;   // 文件系统调用吃栈（未实测到峰值）
static const uint32_t STACK_NET     = 8192;   // WebServer + String 渲染（未实测到峰值）
static const uint32_t STACK_SUPERV  = 3072;

// ---------------------------------------------------------------- 共享状态

static QueueHandle_t      g_recordQ    = nullptr;
static SemaphoreHandle_t  g_latestMux  = nullptr;
// 递归锁：写入路径里可能嵌套调用其它也要锁的函数，
// 普通互斥量在这种情况下会把自己锁死。
static SemaphoreHandle_t  g_storageMux = nullptr;
static String             g_latest;            // ← 被 mux 保护
static volatile bool      g_latestValid = false;

static TaskHandle_t g_hSensor = nullptr, g_hStorage = nullptr,
                    g_hNet = nullptr, g_hSuperv = nullptr;

// 各任务的心跳。监控任务靠它判断谁卡住了。
// volatile + 32 位对齐写入在 Xtensa 上是原子的，所以这几个不用加锁。
static volatile uint32_t g_beatSensor = 0, g_beatStorage = 0, g_beatNet = 0;

// ★ 上板实测修（2026-09-20）
//
// 第一版每 5 秒比一次心跳，不动就报 stalled。但 sensor 的周期是 30 秒——
// 6 次检查里有 5 次它【本来就不该动】，于是每轮都喊 stalled，
// 而那一整段时间它在正常采样。
//
// 这个 bug 比它看起来严重：**一个天天喊狼来了的监控，
// 真出事时没人会信。** 它比没有监控更糟，因为它制造了「已经在看着」的错觉。
//
// 改法：容忍时间不能一刀切，得按各任务【自己的节奏】给。
// 取各自周期的 2 倍再加一点余量 —— 漏掉一个周期算抖动，
// 连着漏两个才是真卡住。
struct BeatWatch {
  volatile uint32_t* beat;
  const char*        name;
  uint32_t           tolerance_ms;   // 超过这么久没动才算卡住
  uint32_t           last;
  uint32_t           last_change_ms;
};

static void publishLatest(const String& rec) {
  // ★ 这里必须加锁：String 的赋值不是原子的（要改指针、长度、可能重新分配堆）。
  // 抢占式调度下，Net 任务可能恰好在"指针已换、长度还没换"的瞬间读到它。
  if (xSemaphoreTake(g_latestMux, pdMS_TO_TICKS(100)) == pdTRUE) {
    g_latest = rec;
    g_latestValid = true;
    xSemaphoreGive(g_latestMux);
  }
}

bool storageLock(uint32_t timeout_ms) {
  if (!g_storageMux) return true;          // 单线程路径，无需加锁
  return xSemaphoreTakeRecursive(g_storageMux, pdMS_TO_TICKS(timeout_ms)) == pdTRUE;
}

void storageUnlock() {
  if (g_storageMux) xSemaphoreGiveRecursive(g_storageMux);
}

bool tasksGetLatest(String& out) {
  if (!g_latestMux || !g_latestValid) return false;
  if (xSemaphoreTake(g_latestMux, pdMS_TO_TICKS(50)) != pdTRUE) return false;
  out = g_latest;
  xSemaphoreGive(g_latestMux);
  return true;
}

// ---------------------------------------------------------------- 任务

static void sensorTask(void*) {
  esp_task_wdt_add(nullptr);
  TickType_t last = xTaskGetTickCount();

  for (;;) {
    g_beatSensor++;
    esp_task_wdt_reset();

    setPeripheralSwitches(true);
    vTaskDelay(pdMS_TO_TICKS(500));          // 外设上电稳定

    int moisture  = getMoisture();
    int batteryMv = getBatteryMv();
    float t = 0.0f, h = 0.0f;
    bool dhtOk = readDht11(t, h);            // ← 这里会阻塞 ~2.5s，Net 任务照跑
    int n = readSpectralChannels(spectralChannels, 12);

    setPeripheralSwitches(false);

    String rec = buildMeasurementRecord(moisture, batteryMv, t, h, dhtOk,
                                        spectralChannels, n);
    publishLatest(rec);                      // 网页立刻就能看到，不用等落盘

    RecordMsg msg;
    snprintf(msg.line, sizeof(msg.line), "%s", rec.c_str());

    // 队列满了就丢最旧的：新鲜数据比积压的旧数据有价值。
    if (xQueueSend(g_recordQ, &msg, 0) != pdTRUE) {
      RecordMsg drop;
      xQueueReceive(g_recordQ, &drop, 0);
      xQueueSend(g_recordQ, &msg, 0);
      Serial.println("[TASK] record queue full, dropped oldest");
    }

    if (batteryShouldShutdown(batteryMv)) {
      // ★ 先拿存储锁再停机。storage 任务可能正写到一半 ——
      // 直接 esp_deep_sleep_start() 会在写入中途掐断电，
      // 损坏的恰恰是 A5 本来要保护的那份数据。
      // 拿到锁 = 没有写入在进行中。拿不到也得走，但至少等满 5s。
      storageLock(5000);
      enterLowBatteryShutdown(batteryMv);    // 不返回
    }

    // vTaskDelayUntil 而不是 vTaskDelay：周期从【上次唤醒时刻】算，
    // 采样本身花掉的 3s 不会累积成漂移。
    vTaskDelayUntil(&last, pdMS_TO_TICKS(SENSOR_PERIOD_MS));
  }
}
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

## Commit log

2026-05-01 Initial ESP32-S3 data logger project
    [partitions.csv]
2026-07-16 Add StarvedLogger PCB design
    [StarvedLogger_PCB.kicad_pcb, StarvedLogger_PCB.kicad_sch]
2026-08-10 Update StarvedLogger PCB design
    [StarvedLogger_PCB.kicad_pcb, StarvedLogger_PCB.kicad_sch]
2026-09-20 A1：页面渲染改为分块流式发送，消除长期运行后的堆耗尽
    原来 handleRoot 调 buildPage()，而 buildPage 把【整个日志文件】拼进一个
    String。每条记录约 150 字节、5 分钟一采 → 一周 300 KB，而 nopsram 版
    可用堆只有约 300 KB（WiFi 栈还要吃掉几十 KB）。
    更阴险的是 String::operator+= 内存不足时【静默失败】：返回被截断的字符串，
    页面显示不全但不报错；而且几百次「分配-拷贝-释放」会把堆打成碎片，
    最先崩的往往是 WiFi 栈——现象是「板子重启了」，查不到这里。
    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
2026-09-20 A4+A6：启用 Task WDT 与资源水位日志
    A4 看门狗：Arduino 默认关掉 task WDT（原型阶段不想被复位），但田里的
    节点卡死 = 报废，只能人去拔电池。SD 总线卡住、传感器不应答、某个 while
    等不到条件——这些都不会自己恢复。
    · display 态 30s：常驻响应 HTTP，超时说明卡在某个请求里
    · logger 态 60s：一轮含 2.5s 外设稳定与 DHT11 时序，留足余量
    · trigger_panic=true —— 超时直接 panic 复位，现场会落进 coredump 分区
    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
2026-09-20 A5+A7：低电压截止与数据质量位
    A5 截止：供电是 4 节 AA，碱性电池没有锂电「过放即报废」的问题，所以这里
    保护的是【数据】不是电池——电压掉到 3.3V LDO 压差余量以下时轨会不稳，
    若恰好发生在 SD 写入中途，坏的是文件甚至整张卡，而那是几个月的数据。
    阈值 3.7V，触发后断外设 + 进【无定时唤醒】深睡，只能靠 EXT0 或换电池唤醒。
    判断点放在写卡【之前】，确保还有电完成落盘。
    A7 质量位：原来读失败写 "nan"，下游分不清「读失败 / 真的是 NaN / 解析错」。
    在 esp32-autoflash 的评测里栽过同一个坑——「读数恒 0」到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
    [main.cpp]
2026-09-20 A3：浏览器对时，给数据补上绝对时间戳
    【问题】记录里格式化时间戳的分支【永远不执行】——条件是 now > 1700000000，
    而全项目没有任何地方设过系统时钟。实际写进文件的只有 time_ms=millis()，
    且 millis() 每次 deep sleep 醒来从 0 重数。靠 sampleCounter 能反推相对
    时间，但没有绝对时间——农业数据的日变化曲线画不出来。
    【为什么不用 NTP】田里没网络回传，设备自己是 AP 不是 STA。
    【为什么不加 RTC 芯片】要改 PCB。
    【解法】用户的手机是唯一会来的那个设备：他打开仪表盘时，页面 JS 顺手把
    浏览器时间回传到 /settime，设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
    [display_gateway.cpp, main.cpp]
2026-09-20 A2：分区表重划为 8MB，占用率 81.8% → 34.1%，并加回 coredump
    原方案抄自 Arduino 的 default_ffat.csv（4MB 板子用的），只改了一行：
    删掉 coredump 把 64KB 给 FFat。两个后果当时没意识到：
    ① 整张表只用到 0x400000 = 4MB，而芯片是 8MB —— 一半 flash 从没被寻址。
    ② Arduino 核心其实启用了 CONFIG_ESP_COREDUMP_ENABLE_TO_FLASH
    （见 esp32s3-libs/3.3.11/sdkconfig）。崩溃现场本该写进 flash，
    不走串口——所以「固件一 panic，CDC 跟着死，日志到不了主机」这个
    问题它本来就能绕过去。但分区被删了 = 无处可写，而且静默失败。
    实测固件 1,074,233 字节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
    [partitions.csv]
2026-09-20 A10：OTA —— 经设备自身 AP 推送固件，并覆盖 verifyOta 做回滚自检
    【为什么现成方案都不适用】
    ArduinoOTA —— 要设备和开发机同局域网、靠 mDNS 推送。田里没网。
    HTTPUpdate —— 设备主动去服务器拉固件。同样要网。
    【这个场景的天然解法】display 模式下设备自己就是 AP + HTTP 服务器：
    走到田里 → 拨 GPIO5 → 重启进 display 模式 → 手机连 AP → /update 上传
    .bin → 重启跑新固件。全程不需要任何网络。带 HTTP Basic 认证——
    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
2026-09-20 A8：FreeRTOS 四任务改造，常驻模式下采样与网页服务并行
    按阻塞原因分任务：sensor(I2C/单总线)、storage(SPI/文件系统)、
    net(socket，与 WiFi 同核)、supervisor(不等任何东西，故能判断谁卡住)。
    采样与存储间用队列解耦，慢一次 SD 写不影响采样节奏。
    队列元素用定长 POD 而非 String——xQueueSend 是 memcpy，
    传 String 只复制堆指针，发送方析构后接收端即悬空。
    logger 模式是深睡眠，保持单线程不动。
2026-09-20 A8：加 FORCE_DISPLAY_MODE 编译期开关，便于无跳线时验证四任务
2026-09-20 A8 修：存储加递归锁，堵住 net 读与 storage 写撞车
    自审四任务代码时发现两个真并发 bug：
    1) net 任务渲染页面时读 SD，storage 任务同时写 SD——
    Arduino 的 SD/SPI 不是线程安全的
    2) 低电压停机直接 esp_deep_sleep_start()，storage 可能正写到一半，
    损坏的恰是 A5 要保护的数据；停机前先拿锁等写入结束
    用 RAII guard 而非手工配对，避免提前返回路径漏掉解锁
    [main.cpp, tasks.cpp]
2026-09-20 A5 修：悬空 ADC 会让节点把自己睡死，上板实测发现
    判据写的是 batteryMv > 0，本意是「读数有效」，但 ADC 悬空时读到的
    是几百 mV 噪声，不是 0。裸板上电不到 1 秒就执行永久停机，
    USB 从系统消失，只能按 RESET 救。田里分压虚焊/接触不良同理。
    两道闸：合理性下限 1000mV（4×AA 经 ÷3 分压再空也在 3V 以上，
    低于 1V 说明没接电池而非没电）+ 连续 3 次才认。
    停机改为 6 小时定时唤醒复检，占空比仍接近 0 但可自行恢复。
    verifyOta 里同一处判据一并修——否则分压虚焊会让每次 OTA 静默回滚。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
    [main.cpp, tasks.cpp]
2026-09-20 A5 二修：上一版判据是错的，上板又睡死一次才发现
    第一版下限 1000mV，依据是「悬空 ADC 读数低」——这个假设不成立。
    悬空引脚读随机中间值，分压 3:1 之下 ADC 落在 0.33~1.23V 就换算成
    1.0~3.7V，正好落进低电量窗口。加连续判定只是把 1 秒睡死变成 90 秒睡死。
    按物理量重定：4×AA 碱性，0.9V/节=3.6V 已耗尽，故 3.7V 截止正确；
    3.0V(0.75V/节)是深度放空，能跑 WiFi 的节点不可能读到——读到只能是
    线路断了。下限提到 3000mV。
    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
2026-09-20 A8 修：supervisor 卡死判定改成按各任务自己的节奏，栈深按实测调整
    上板实测发现 supervisor 每轮都报 sensor stalled，而 sensor 正常工作——
    它每 5 秒比一次心跳，sensor 周期却是 30 秒，6 次里 5 次本来就不该变。
    一个天天喊狼来了的监控比没有监控更糟，它制造了「已经在看着」的错觉。
    改成每个任务声明自己的容忍时间（周期 2 倍 + 余量）。
    栈深换成实测值：sensor 4096 剩 1500（余量仅 37%）故提到 5120；
    storage/net 的数字保留但标注不可用作结论——测试板没插 SD、
    没发 HTTP，两者最吃栈的路径都没执行。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
    [tasks.cpp]
2026-09-21 把台面电池旁路从 FORCE_DISPLAY_MODE 里拆出来
    两个开关是两件事：FORCE_DISPLAY_MODE 是「没接跳线」，
    BENCH_NO_BATTERY 是「没接电池」。第一版把旁路写在前者的 #ifdef 里，
    结果台面验证时 batteryShouldShutdown 一进来就返回，
    下面的合理性下限和稳定性判据【一次都没在真硬件上跑过】——
    而它们恰恰是那个把板子睡死两次的 bug 的修复本身。
    耦合两个无关的开关，等于让其中一个永远测不到。
    [main.cpp]
2026-10-30 SD 卡四条线按 PCB 网表改正，补引脚对照表
    原来 SDcardPin=T12(GPIO12) 加裸 SPI.begin()，后者走 Feather variant 的默认值。
    对照 StarvedLogger_PCB 的 J3 实际接线，四条线错三条，且刚好互相串位：
    旧 MOSI(35) 是实际的 CS，旧 SCK(36) 是实际的 MOSI，只有 MISO(37) 碰巧对。
    往 CS 线上发时钟、拿 MOSI 当片选，SD.begin() 不可能成功。
    改成显式 SPI.begin(38,37,36,35) + SD.begin(35,...)。上板实测写入→读回→
    逐字节比对连续 14 轮全部 match，文件字节数单调递增。
    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
2026-10-30 引脚全面对齐 PCB：modePin 换脚、I2C/DHT11/电池 ADC 改正、补 SSR 供电
    六处引脚常量原本照 Adafruit Feather 的 variant 写，不是照本板：
    modePin GPIO5 → GPIO12 原来和 DHT11 撞脚，模块上拉让它恒 HIGH，
    固件永远进 display、永远进不了 logger
    sensor1Pin A3(15) → 5 DHT11 在 J5 脚3，经 R5 1k 接 GPIO5
    batteryAdcPin A2(16) → 2 /BAT_SENSE 接 U1 封装脚 6
    Wire.begin (3,4) → (8,9) 本板 3.3V I2C
    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
2026-10-30 采集循环加入 TMP117 板载温度；记录 ADC 链路实测
    TMP117(U2 @ 0x48) 进两条采样路径（logger 模式的 loop 和四任务模式的 Sensor 任务）。
    不引库：寄存器就三个，裸 I2C 比多一个依赖干净。
    initTmp117() 的判据是【器件 ID 必须等于 0x0117】，不是「地址有应答」——
    地址应答只说明总线上有东西，读到正确 ID 才说明那东西是 TMP117。
    记录新增 board_temp_c 和 tmp_q 两个字段。质量位写法跟 dht_q 一致（A7 那条理由）。
    board_temp_c 和 temp_c 是两回事，不要合并：DHT11 量的是 J5 外接探头处的环境温度，
    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
2026-10-30 修正 ADC 满量程的算法：用实测外推，不用标称值
    原来写「4×AA 全新 6.4V 会削顶」，依据是手册标称的「11dB 满量程 3100mV」。
    用实测两点外推更准：raw 3495 ↔ 2828mV，则 raw 4095 ↔ 3313mV，
    对应电池端 6.63V 才饱和。6.4V 对应 raw≈3954，擦边但仍在量程内。
    同时标注四档衰减的对比扫描不可信、别照抄：analogSetPinAttenuation() 要在
    该引脚首次 analogRead() 之前设才生效，运行中切换不完全生效（0dB 那行读出的
    其实是默认档的值）。结论只用稳态 11dB 那组数据。
    分压比确认：J2 接 6V 电池，比值 1:2，与网表 R11/R10 各 10k 一致。
    代码里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
2026-10-30 修 setPeripheralSwitches 驱动 I2C 引脚；modePin 下拉；SD 上电标记行
    ★ setPeripheralSwitches() 在本板上是有害的，改为委托 enableSensorRails()：
    switch1Pin = T10 = GPIO10 -> /I2C_SDA 5v
    switch2Pin = T6 = GPIO6 -> 网表里根本没有 IO6（未连接）
    switch3Pin = T9 = GPIO9 -> /I2C_SCL 3.3V
    原来对这三个脚 digitalWrite，等于把两条 I2C 线当推挽输出驱动。
    logger 模式侥幸能用，因为每次深睡醒来 setup() 重跑、Wire.begin() 把引脚抢回去；
    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
2026-10-30 DHT11 判据收严到湿度；深睡期间用 RTC 焊盘保持 modePin 下拉
    ★ readDht11 判据：isnan 之外再判 humidity <= 0。
    归因固件实测，传感器那一路断电再上电之后：
    i=1 err=TIMEOUT t=nan h=nan isnan 挡得住
    i=2 err=OK t=0.8 h=0.0 ← 库说成功，数据是垃圾
    i=3 err=OK t=26.8 h=22.0 第三次才真有效
    第二次那种「成功的垃圾」getStatus() 返回 ERROR_NONE、isnan() 也过得去，
    而项目每轮采样之间都断电，所以每次醒来都会撞上它。
    第一版判据写的是 h==0 && t==0（要两个都为零），而实测垃圾是 t=0.60 h=0.00，
    温度不为零就放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
2026-10-30 记录改为每小时一条；标记行只在真正上电时写
    ★ RECORD_EVERY_SAMPLE_COUNT 从写死的 50 改为从唤醒周期推导：
    LOGGER_CYCLE_MS = AWAKE_DURATION_MS + SLEEP_DURATION_US/1000 (20s + 10s)
    RECORD_EVERY_SAMPLE_COUNT = 3600000 / LOGGER_CYCLE_MS (= 120)
    原来写死 50 的含义依赖当时的醒/睡时长（一轮一个样本 → 25 分钟一条）。
    改了任一时长这个数就悄悄变成别的意思，而注释不会跟着变。
    推导出来则「一小时一条」这个意图被编码进代码，改时长也不漂。
    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
2026-11-09 启用土壤湿度 VH400：信号走 GPIO14，带三态在位检测
    J7 的信号脚是 GPIO21，而 ESP32-S3 的 ADC 只到 GPIO20（依据
    soc/esp32s3/adc_channel.h），analogRead(21) 不报错但返回垃圾。
    信号改接 J8 第3脚 = GPIO14 = ADC2_CH3；电源和地留在 J7
    （J8 整排无 GND 脚）。VH400 输出固定 0~3V 不随供电摆动，
    6V 供电安全，无需分压。
    - 新增官方 5 段 VWC 曲线（网上转载普遍漏掉第 5 段）。已验算：
    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
2026-11-09 修在位判据：改判两条轨而非极差，不再依赖未验证的片内拉阻
    上一版判据 `spread > 1500mV` 依赖「片内上下拉约 45kΩ」这个没验证过的
    数字。若实际是 10kΩ，在位时极差 3300*10/20 = 1650mV 就会越过阈值，
    把工作中的传感器每轮误判成 absent、vwc_pct 恒 nan —— 加的"安全检查"
    反而杀掉好数据。
    改成 (vDown < 150mV) AND (vUp > 3100mV)：10kΩ 源阻抗不可能同时被拉到
    两条轨。片内拉阻 10k/20k/45k/80k × VH400 输出 0/0.5/1/2/3V 共 20 种
    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
2026-11-09 一分钟一轮、一小时一条：睡眠时长反算，计数改存 RTC noinit
    频率：CYCLE_PERIOD_MS = 60s，睡眠时长不再写死，而是睡前用
    「周期 − millis()」反算（millis() 在深睡唤醒后从 0 起，就是本轮醒着
    的时长）。原来按「醒 20s + 睡 10s = 30s 一轮」推出 120 轮一小时，
    但实测一轮 36.6s —— 采样工作比 AWAKE_DURATION_MS 多出约 6.6s，
    那个推导假设两者相等，结果「每小时一条」实际是 73 分钟，偏 22%。
    反算之后采样快慢不再影响周期。
    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
